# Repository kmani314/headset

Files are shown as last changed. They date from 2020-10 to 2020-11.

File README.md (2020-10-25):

# MR Headset

This is an open-source **Mixed Reality** headset that aims to augment the power of human imagination. It aims to do this by using high resolution displays and cameras, as well as a powerful ARM based CPU and GPU. 

Version 0.1 of the mainboard is avaiable in `/hardware/mainboard`, it is designed around an RK3399-based SOM.

[BOM](https://docs.google.com/spreadsheets/d/1svv3ELyh4oFGVD46yAfUMj0UHieJaqO5vQMvadlOVdQ/edit?usp=sharing)

[Digi-Key Shared BOM (Requires account)](https://www.digikey.com/BOM/Create/CreateSharedBom?bomId=8410949)

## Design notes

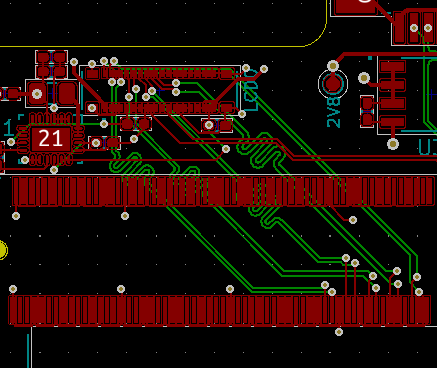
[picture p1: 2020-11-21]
pcb.png

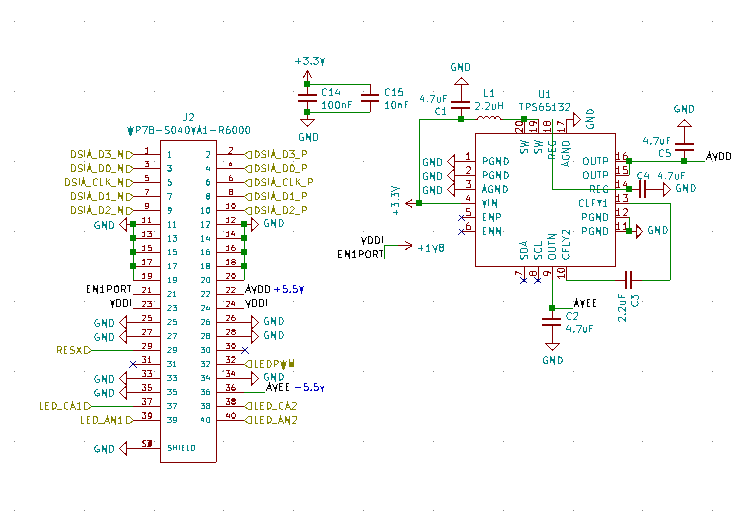
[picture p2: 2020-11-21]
sch.png

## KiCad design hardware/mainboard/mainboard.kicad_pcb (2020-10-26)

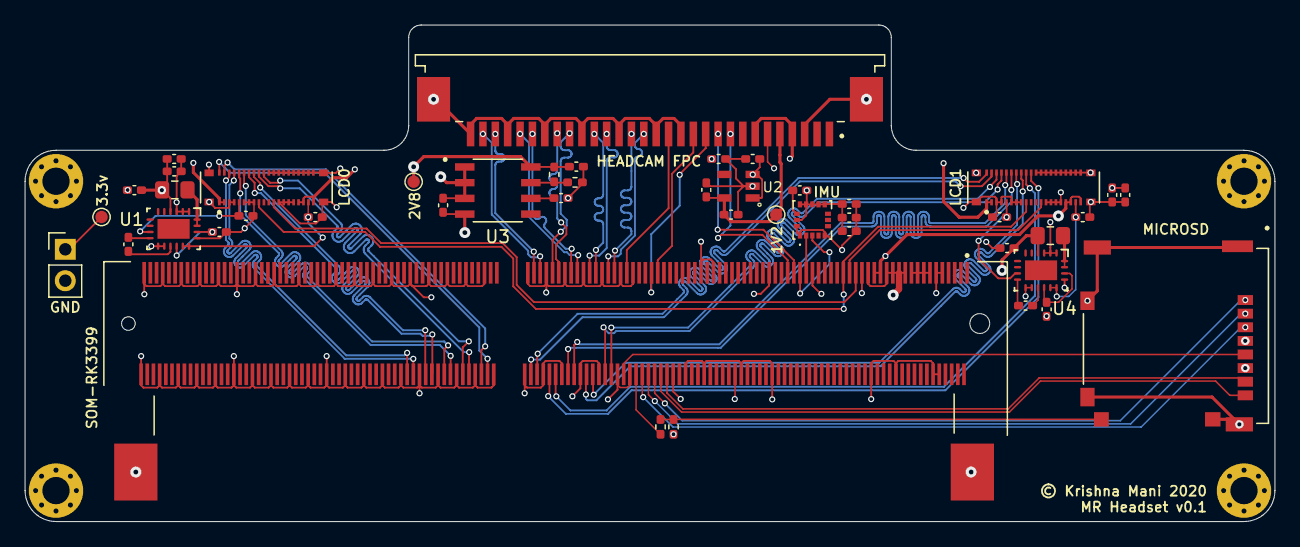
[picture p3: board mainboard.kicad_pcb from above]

Board: 4 copper layers, 101.0 x 40.1 mm, 49 parts (0 on the bottom side), 69 nets.

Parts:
C1, C2, C4, C5, C11, C18, C19, C21, C22: 4.7uF; C_0402_1005Metric_Pad0.74x0.62mm_HandSolder
C3, C20, C24: 2.2uF; C_0402_1005Metric_Pad0.74x0.62mm_HandSolder
C6, C7, C13: 1uF; C_0402_1005Metric_Pad0.74x0.62mm_HandSolder
C8, C10, C14, C16: 100nF; C_0402_1005Metric_Pad0.74x0.62mm_HandSolder
C9, C15, C17, C25: 10nF; C_0402_1005Metric_Pad0.74x0.62mm_HandSolder
C23, C26: 0.1uF; C_0402_1005Metric_Pad0.74x0.62mm_HandSolder
H1, H2, H3, H4: MountingHole_Pad; MountingHole_2.2mm_M2_Pad_Via
J1: 2309407-1; TE_2309407-1
J2, J6: WP7B-S040VA1-R6000; JAE_WP7B-S040VA1-R6000
J3: Conn_01x02_Male; PinHeader_1x02_P2.54mm_Vertical
J4: 3-84953-0; TE_3-84953-0
J5: 503182-1852; MOLEX_503182-1852
L1, L2: 2.2uH; L_0805_2012Metric_Pad1.15x1.40mm_HandSolder
R1: 60k; R_0402_1005Metric_Pad0.72x0.64mm_HandSolder
R2, R4: 10k; R_0402_1005Metric_Pad0.72x0.64mm_HandSolder
R3: 1k; R_0402_1005Metric_Pad0.72x0.64mm_HandSolder
TP1, TP3, TP4: TestPoint; TestPoint_Pad_D1.0mm
U1, U4: TPS65132; TPS65132WRVCT
U2: MIC5504-1.2YM5-TR; SOT23-5P95_280X145XL45X37N
U3: MCP1725-ADJE_MC; SOIC127P599X175-8N
U5: ICM-20602; PQFN50P300X300X80-16N

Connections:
+1V2: C7.1, C10.1, J4.5, TP1.1, U2.5
+1V8: C24.2, C25.2, C26.1, J1.29, J1.31, J2.21, J2.23, J2.24, J4.6, J6.21, J6.23, J6.24, U5.1, U5.5, U5.16
+2V8: C8.1, C13.1, J2.39, J2.40, J4.4, J4.7, J6.39, J6.40, R1.1, TP4.1, U3.8
+3V3: C1.1, C6.1, C11.1, C14.1, C15.1, C16.1, C17.1, C18.1, J1.21, J1.23, J1.25, J1.27, J1.33, J1.76, J3.1, J5.4, L1.1, L2.1, R4.2, TP3.1, U1.4, U2.1, U2.3, U3.1, U3.2, U3.3, U4.4
+5V: J1.13, J1.15, J1.17, J1.19
/GPIO2_B3_CIF_CLKOUTA: J1.111, J4.14
/GPIO_BL: J1.41, J2.32, J6.32
/I2C1_SCL: J1.53, U5.2
/I2C1_SDA: J1.55, U5.3
/I2C2_SCL: J1.59, J4.9
/I2C2_SDA: J1.57, J4.10
/LCD 1/AVDD: C5.1, J2.22, U1.15, U1.16
/LCD 1/AVEE: C2.1, J2.36, U1.9
/LCD 2/AVDD: C22.1, J6.22, U4.15, U4.16
/LCD 2/AVEE: C19.1, J6.36, U4.9
/MIPI_CSI0_PWN: J1.101, J4.12
/MIPI_CSI1_RST: J1.103, J4.11
/MIPI_RX0_CLK+: J1.129, J4.25
/MIPI_RX0_CLK-: J1.127, J4.26
/MIPI_RX0_D0+: J1.141, J4.28
/MIPI_RX0_D0-: J1.139, J4.29
/MIPI_RX0_D1+: J1.135, J4.22
/MIPI_RX0_D1-: J1.133, J4.23
/MIPI_RX0_D2+: J1.123, J4.19
/MIPI_RX0_D2-: J1.121, J4.20
/MIPI_RX0_D3+: J1.117, J4.16
/MIPI_RX0_D3-: J1.115, J4.17
/MIPI_TX0_CLK+: J1.162, J2.6
/MIPI_TX0_CLK-: J1.160, J2.5
/MIPI_TX0_D0+: J1.174, J2.4
/MIPI_TX0_D0-: J1.172, J2.3
/MIPI_TX0_D1+: J1.168, J2.8
/MIPI_TX0_D1-: J1.166, J2.7
/MIPI_TX0_D2+: J1.156, J2.10
/MIPI_TX0_D2-: J1.154, J2.9
/MIPI_TX0_D3+: J1.150, J2.2
/MIPI_TX0_D3-: J1.148, J2.1
/MIPI_TX1_CLK+: J1.130, J6.6
/MIPI_TX1_CLK-: J1.128, J6.5
/MIPI_TX1_D0+: J1.118, J6.4
/MIPI_TX1_D0-: J1.116, J6.3
/MIPI_TX1_D1+: J1.124, J6.8
/MIPI_TX1_D1-: J1.122, J6.7
/MIPI_TX1_D2+: J1.136, J6.10
/MIPI_TX1_D2-: J1.134, J6.9
/MIPI_TX1_D3+: J1.142, J6.2
/MIPI_TX1_D3-: J1.140, J6.1
/RESX_0: J1.37, J2.29
/RESX_1: J1.39, J6.29
/SDMMC0_CLK: J1.112, J5.5
/SDMMC0_CMD: J1.106, J5.3
/SDMMC0_D0: J1.98, J5.7
/SDMMC0_D1: J1.100, J5.8
/SDMMC0_D2: J1.102, J5.1
/SDMMC0_D3: J1.104, J5.2
/SDMMC0_DET_L: J1.108, R3.2
GND: C1.2, C2.2, C4.1, C5.2, C6.2, C7.2, C8.2, C9.2, C10.2, C11.2, C13.2, C14.2, C15.2, C16.2, C17.2, C18.2, C19.2, C21.1, C22.2, C23.1, C24.1, C25.1, C26.2, H1.1, H2.1, H3.1, H4.1, J1.9, J1.10, J1.11, J1.12, J1.24, J1.32, J1.35, J1.51, J1.64, J1.65, J1.74, J1.83, J1.86, J1.87, J1.92, J1.96, J1.109, J1.110, J1.113, J1.114, J1.119, J1.120, J1.125, J1.126, J1.131, J1.132, J1.137, J1.138, J1.143, J1.144, J1.146, J1.149, J1.152, J1.155, J1.158, J1.161, J1.164, J1.167, J1.170, J1.173, J1.176, J1.179, J1.182, J1.185, J1.188, J1.191, J1.194, J1.197, J1.200, J1.203, J1.206, J1.209, J1.212, J1.217, J1.218, J1.223, J1.224, J1.229, J1.230, J1.235, J1.236, J1.241, J1.242, J1.247, J1.248, J1.253, J1.254, J1.259, J1.260, J1.SH1, J1.SH2, J2.11, J2.12, J2.13, J2.14, J2.15, J2.16, J2.17, J2.18, J2.19, J2.20, J2.25, J2.26, J2.27, J2.28, J2.33, J2.34, J2.35, J2.37, J2.38, J2.S1, J2.S2, J2.S3, J2.S4, J3.2, J4.3, J4.13, J4.15, J4.18, J4.21, J4.24, J4.27, J4.30, J4.S1, J4.S2, J5.6, J5.P1, J5.P2, J5.P3, J5.P4, J5.P5, J5.SW, J6.11, J6.12, J6.13, J6.14, J6.15, J6.16, J6.17, J6.18, J6.19, J6.20, J6.25, J6.26, J6.27, J6.28, J6.33, J6.34, J6.35, J6.37, J6.38, J6.S1, J6.S2, J6.S3, J6.S4, R2.2, U1.1, U1.2, U1.3, U1.11, U1.12, U1.17, U2.2, U3.4, U4.1, U4.2, U4.3, U4.11, U4.12, U4.17, U5.9, U5.10, U5.11, U5.12, U5.13, U5.15
unnamed: C3.1, U1.13
unnamed: C3.2, U1.10
unnamed: C4.2, U1.14, U1.18
unnamed: C9.1, U3.6
unnamed: C20.1, U4.13
unnamed: C20.2, U4.10
unnamed: C21.2, U4.14, U4.18
unnamed: C23.2, U5.14
unnamed: J5.DT, R3.1, R4.1
unnamed: L1.2, U1.19, U1.20
unnamed: L2.2, U4.19, U4.20
unnamed: R1.2, R2.1, U3.7

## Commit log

2020-10-14 Initial commit, rk3399 chosen, initial stuff done in pcb
    [camera_subsystem.sch, lcd_subsystem.sch, mainboard.kicad_pcb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]
2020-10-18 displays done, sd card and camera is left
    [lcd_subsystem.sch, mainboard.sch]
2020-10-19 finished camera, sd, imu, power supplies, might be done with schematic
    [camera_subsystem.sch, lcd_subsystem.sch, mainboard.sch]
2020-10-19 footprints assigned, ready to begin pcb design
    [lcd_subsystem.sch, mainboard.kicad_pcb, mainboard.sch]
2020-10-24 mipi done, power almost done
    [lcd_subsystem.sch, mainboard.kicad_pcb, mainboard.sch]
2020-10-24 0.1 routing done, will merge after cleaning up silkscreen
    [lcd_subsystem.sch, mainboard.kicad_pcb, mainboard.sch]
2020-10-24 fixed silkscreen
    [mainboard.kicad_pcb]
2020-10-24 add fpc
    [mainboard.kicad_pcb, mainboard.sch]
2020-10-25 add shared bom
2020-10-26 minor fix
    [mainboard.kicad_pcb]

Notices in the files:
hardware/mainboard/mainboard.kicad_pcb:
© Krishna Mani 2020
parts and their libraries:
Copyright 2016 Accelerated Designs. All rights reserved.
